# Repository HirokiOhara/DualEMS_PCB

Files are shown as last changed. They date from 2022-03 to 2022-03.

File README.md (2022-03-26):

# EiMS_PCB
ahs2022-24 001

This repository contains source code of software from our work "DualEMS: Two-Channel Arbitrary Waveform Electrical Muscle Stimulation Device to Design Interference Stimulation" (ACM AHs2022).

## Hardware Implimentation
HardwareImplimentation

## Authors
Hiroki Ohara, Tokyo Tech ( h.ohara[at]gs.haselab.net )

## Citation
When using or building upon this device/work in an academic publication, please consider citing as follows:
```
Hiroki Ohara and Shoichi Hasegawa. 2022. DualEMS: Two-Channel Arbitrary Waveform Electrical Muscle Stimulation Device to Design Interference Stimulation. In Augmented Humans 2022 (AHs 2022), March 13–15, 2022, Kashiwa, Chiba, Japan. ACM, New York, NY, USA, 8 pages. https://doi.org/10.1145/3519391.3519415
```

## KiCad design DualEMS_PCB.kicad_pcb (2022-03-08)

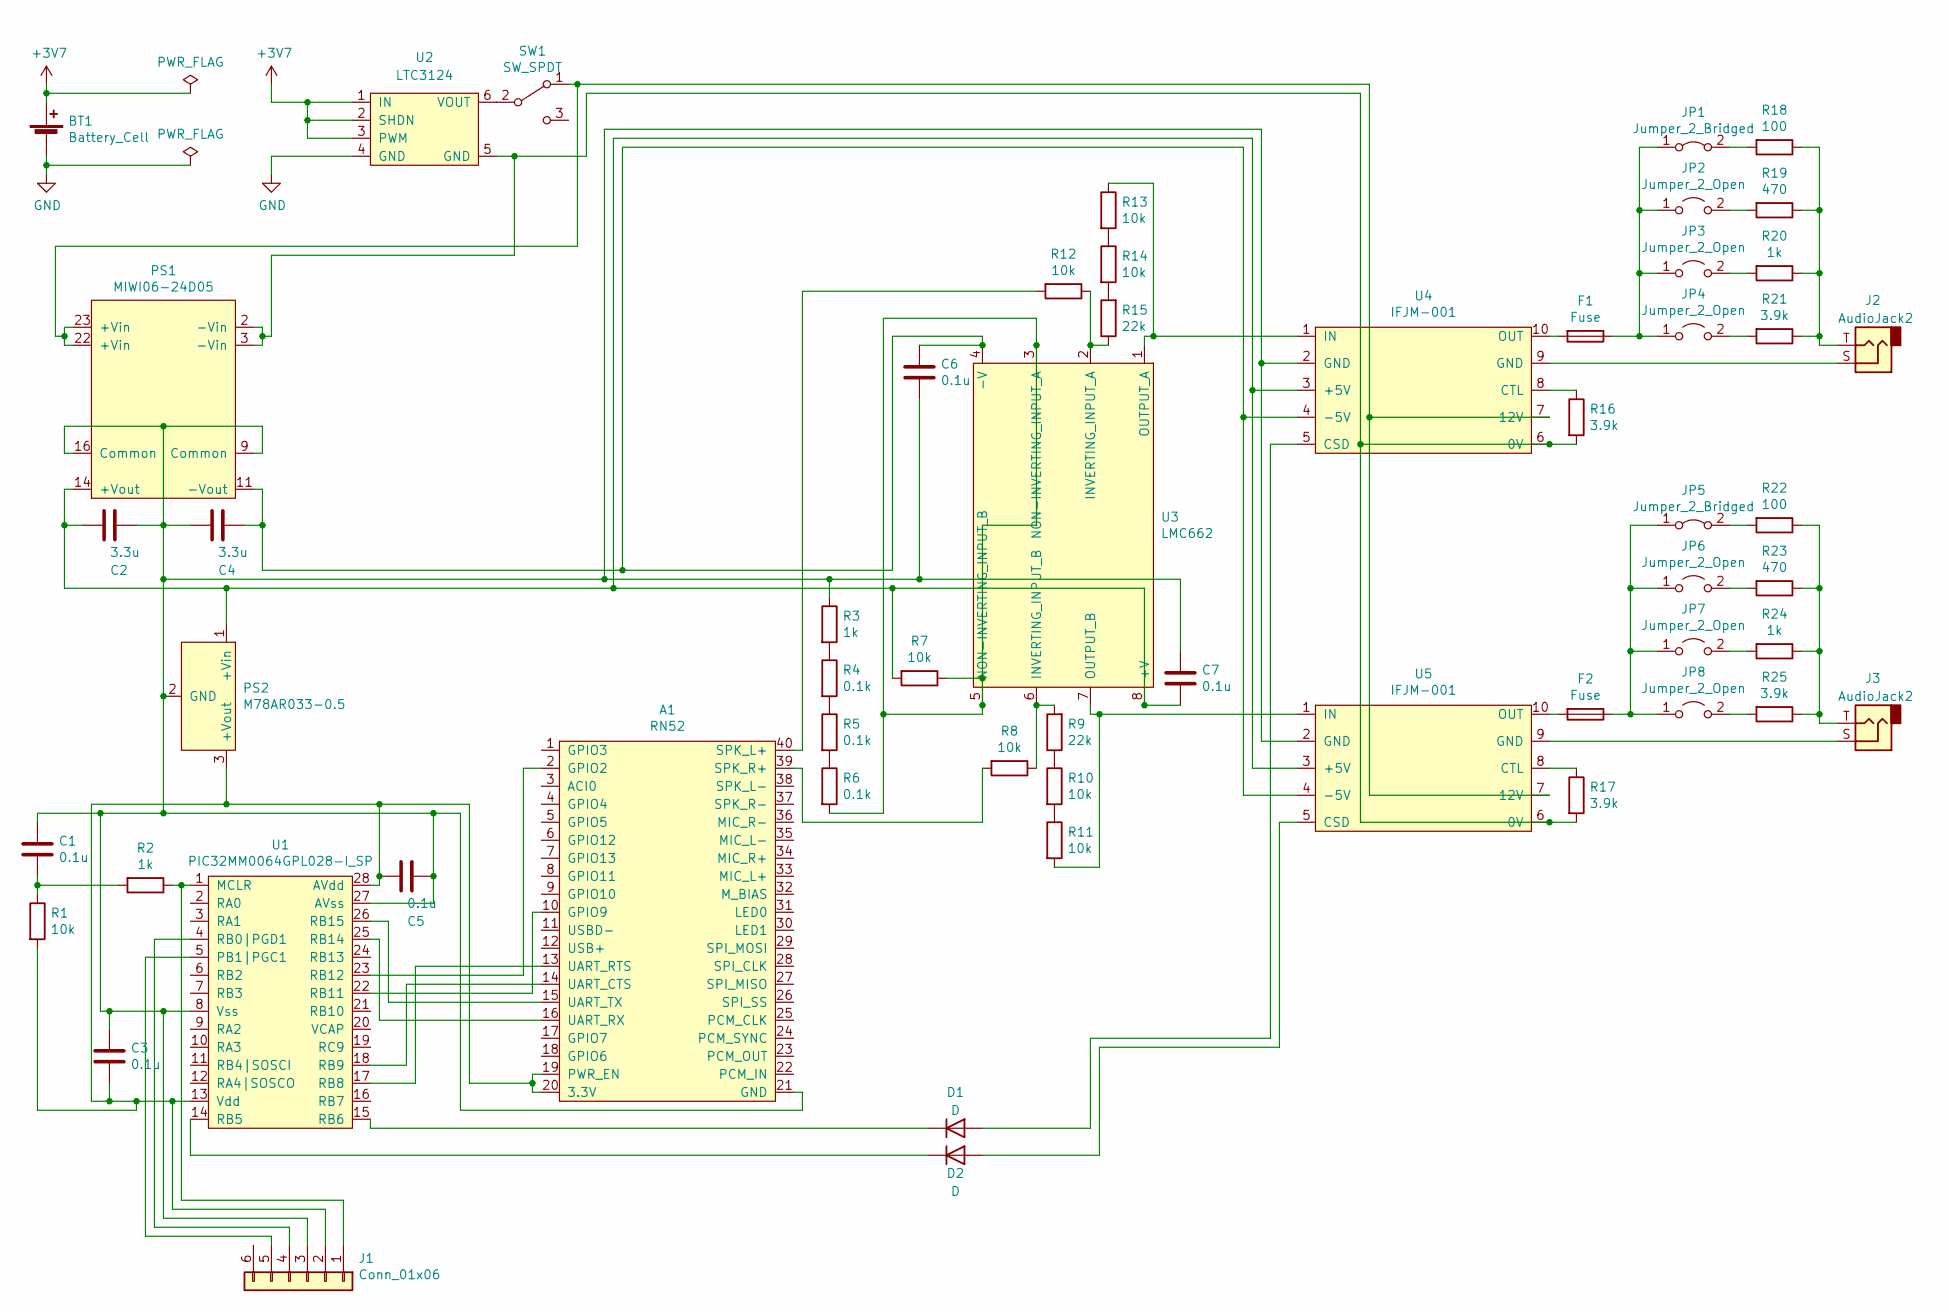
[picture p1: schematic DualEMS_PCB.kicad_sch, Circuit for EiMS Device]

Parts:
A1: RN52
BT1: Battery_Cell; Battery_+3V7
C1, C3, C5, C6, C7: 0.1u; C_Radial_P5.00mm
C2, C4: 3.3u; C_Radial_P5.00mm
D1, D2: D; D_A-405_P10.16mm_Horizontal
F1, F2: Fuse; FUC-04
J1: Conn_01x06; PinHeader_1x06_P2.54mm_Horizontal
J2, J3: AudioJack2; MJ-352
JP1, JP5: Jumper_2_Bridged; PinHeader_1x02_P2.54mm_Vertical
JP2, JP3, JP4, JP6, JP7, JP8: Jumper_2_Open; PinHeader_1x02_P2.54mm_Vertical
PS1: MIWI06-24D05
PS2: M78AR033-0.5
R1, R7, R8, R10, R11, R12, R13, R14: 10k; R_Axial_DIN0207_L6.3mm_D2.5mm_P7.62mm_Horizontal
R2, R3, R20, R24: 1k; R_Axial_DIN0207_L6.3mm_D2.5mm_P7.62mm_Horizontal
R4, R5, R6: 0.1k; R_Axial_DIN0207_L6.3mm_D2.5mm_P7.62mm_Horizontal
R9, R15: 22k; R_Axial_DIN0204_L3.6mm_D1.6mm_P5.08mm_Horizontal
R16, R17, R21, R25: 3.9k; R_Axial_DIN0207_L6.3mm_D2.5mm_P7.62mm_Horizontal
R18, R22: 100; R_Axial_DIN0207_L6.3mm_D2.5mm_P7.62mm_Horizontal
R19, R23: 470; R_Axial_DIN0207_L6.3mm_D2.5mm_P7.62mm_Horizontal
SW1: SW_SPDT; MS-500A-MF-K
U1: PIC32MM0064GPL028-I_SP
U2: LTC3124
U3: LMC662
U4, U5: IFJM-001

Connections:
+3V7: BT1.1 (+), U2.1 (IN), U2.2 (SHDN), U2.3 (PWM)
GND: BT1.2 (-), U2.4 (GND)
unnamed: A1.2 (GPIO2), U1.23 (RB12)
unnamed: A1.10 (GPIO9), U1.22 (RB11)
unnamed: A1.13 (UART_RTS), U1.17 (RB8)
unnamed: A1.14 (UART_CTS), U1.18 (RB9)
unnamed: A1.15 (UART_TX), U1.26 (RB15)
unnamed: A1.16 (UART_RX), U1.25 (RB14)
unnamed: A1.19 (PWR_EN), A1.20 (3.3V), C3.2, C5.1, J1.2, PS2.3 (+Vout), R1.2, U1.13 (Vdd), U1.28 (AVdd)
unnamed: A1.21 (GND), C1.1, C2.2, C3.1, C4.1, C5.2, C6.1, C7.2, J1.3, PS1.9 (Common), PS1.16 (Common), PS2.2 (GND), R3.1, U1.8 (Vss), U1.27 (AVss), U4.2 (GND), U5.2 (GND)
unnamed: A1.39 (SPK_R+), R8.2
unnamed: A1.40 (SPK_L+), R12.2
unnamed: C1.2, R1.1, R2.2
unnamed: C2.1, C7.1, PS1.14 (+Vout), PS2.1 (+Vin), R7.2, U3.8 (+V), U4.3 (+5V), U5.3 (+5V)
unnamed: C4.2, C6.2, PS1.11 (-Vout), U3.4 (-V), U4.4 (-5V), U5.4 (-5V)
unnamed: D1.1 (K), U1.15 (RB6)
unnamed: D1.2 (A), U4.5 (CSD)
unnamed: D2.1 (K), U1.14 (RB5)
unnamed: D2.2 (A), U5.5 (CSD)
unnamed: F1.1, JP1.1 (A), JP2.1 (A), JP3.1 (A), JP4.1 (A)
unnamed: F1.2, U4.10 (OUT)
unnamed: F2.1, JP5.1 (A), JP6.1 (A), JP7.1 (A), JP8.1 (A)
unnamed: F2.2, U5.10 (OUT)
unnamed: J1.1, R2.1, U1.1 (MCLR)
unnamed: J1.4, U1.4 (RB0|PGD1)
unnamed: J1.5, U1.5 (PB1|PGC1)
unnamed: J2.S, U4.9 (GND)
unnamed: J2.T, R18.1, R19.1, R20.1, R21.1
unnamed: J3.S, U5.9 (GND)
unnamed: J3.T, R22.1, R23.1, R24.1, R25.1
unnamed: JP1.2 (B), R18.2
unnamed: JP2.2 (B), R19.2
unnamed: JP3.2 (B), R20.2
unnamed: JP4.2 (B), R21.2
unnamed: JP5.2 (B), R22.2
unnamed: JP6.2 (B), R23.2
unnamed: JP7.2 (B), R24.2
unnamed: JP8.2 (B), R25.2
unnamed: PS1.2 (-Vin), PS1.3 (-Vin), R16.2, R17.2, U2.5 (GND), U4.6 (0V), U5.6 (0V)
unnamed: PS1.22 (+Vin), PS1.23 (+Vin), SW1.1 (A), U4.7 (12V), U5.7 (12V)
unnamed: R3.2, R4.1
unnamed: R4.2, R5.1
unnamed: R5.2, R6.1
unnamed: R6.2, R7.1, U3.3 (NON-INVERTING_INPUT_A), U3.5 (NON-INVERTING_INPUT_B)
unnamed: R8.1, R9.2, U3.6 (INVERTING_INPUT_B)
unnamed: R9.1, R10.1
unnamed: R10.2, R11.1
unnamed: R11.2, U3.7 (OUTPUT_B), U5.1 (IN)
unnamed: R12.1, R15.1, U3.2 (INVERTING_INPUT_A)
unnamed: R13.1, U3.1 (OUTPUT_A), U4.1 (IN)
unnamed: R13.2, R14.1
unnamed: R14.2, R15.2
unnamed: R16.1, U4.8 (CTL)
unnamed: R17.1, U5.8 (CTL)
unnamed: SW1.2 (B), U2.6 (VOUT)

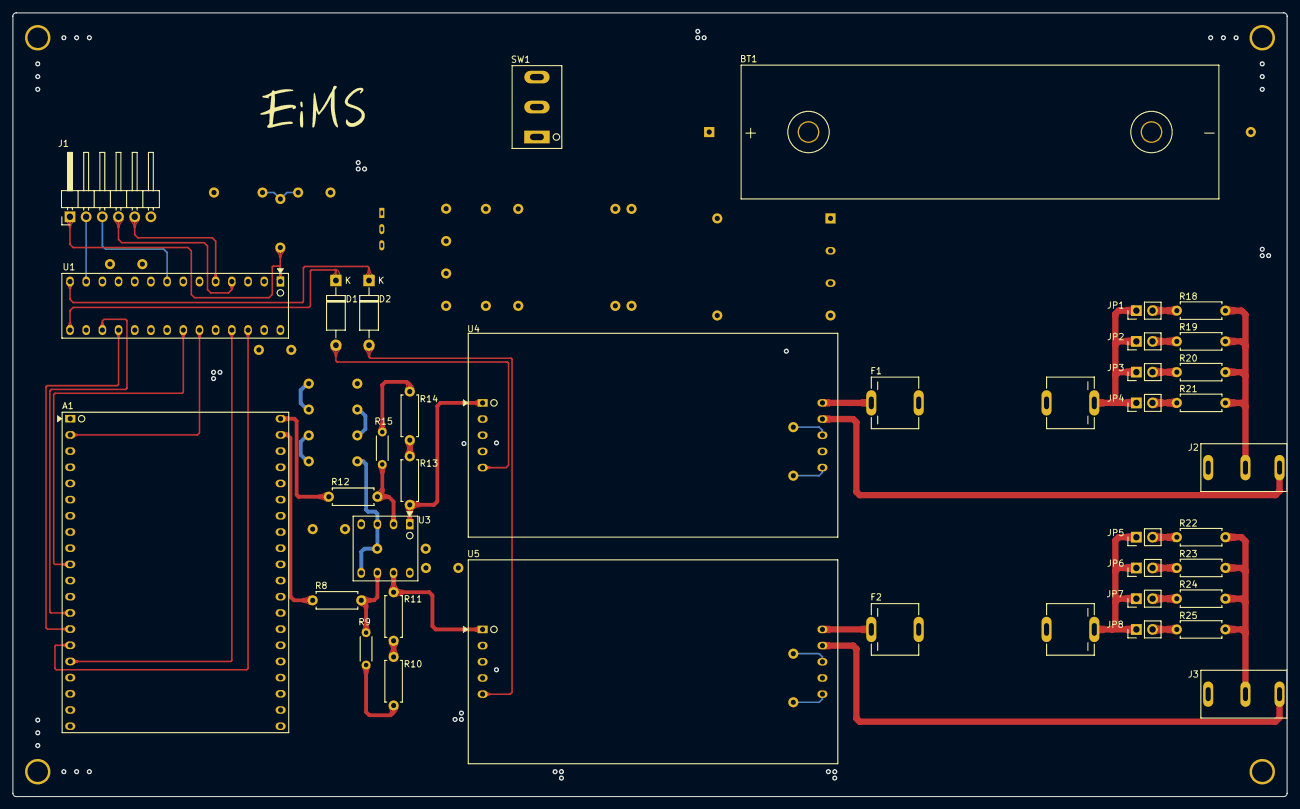
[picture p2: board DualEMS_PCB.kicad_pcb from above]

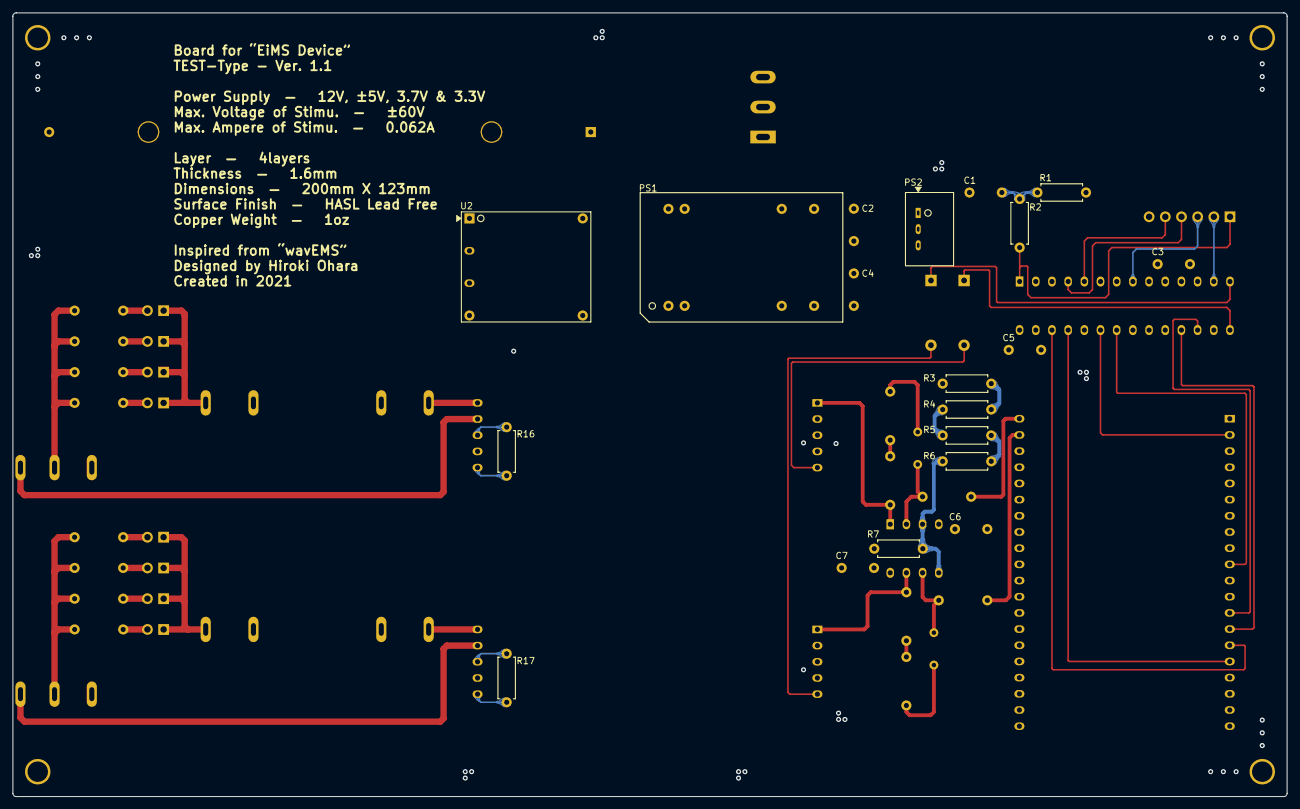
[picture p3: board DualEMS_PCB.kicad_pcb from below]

Board: 4 copper layers, 200.0 x 123.0 mm, 61 parts (19 on the bottom side), 55 nets.

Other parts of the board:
REF1, REF2, REF3, REF4: MountingHole_3.2mm_M3_Pad

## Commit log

2022-03-08 changed name
    [DualEMS_PCB.kicad_pcb, DualEMS_PCB.sch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]
2022-03-08 updated for kiCad 6.0
    [DualEMS_PCB.kicad_pcb, DualEMS_PCB.kicad_sch, DualEMS_PCB.sch]
